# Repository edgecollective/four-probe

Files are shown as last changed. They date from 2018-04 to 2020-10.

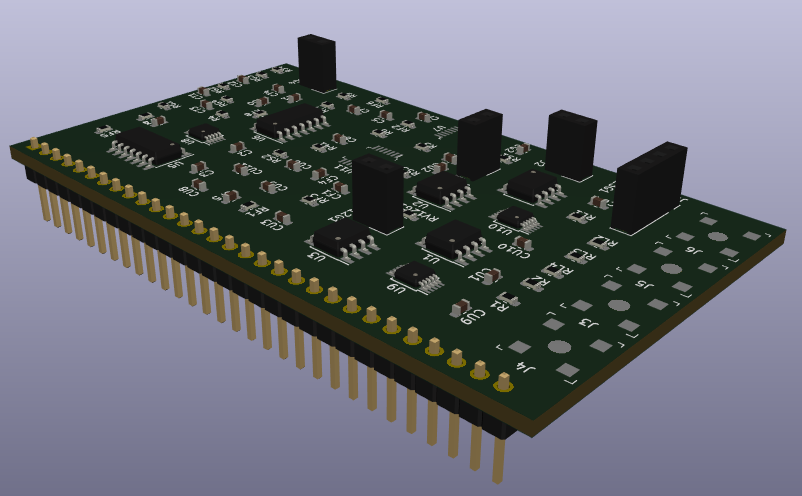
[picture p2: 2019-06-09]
v_0.9/four_probe_0.9_mockup_side.png

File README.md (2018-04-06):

# four-probe

# Timers

- Great examples of using the samd21 timers and interrupts: https://github.com/maxbader/arduino_tools/tree/master/libraries

- Another great example: https://github.com/nebs/arduino-zero-timer-demo/blob/master/src/main.cpp

# Circuit

- Analog Devices "Fully Automatic Self-Calibrated Conductivity Measurements": http://www.analog.com/en/analog-dialogue/articles/fully-automatic-self-calibrated-conductivity-measurement-system.html;  Reference design document: http://www.analog.com/media/en/reference-design-documentation/reference-designs/CN0359.pdf

# Misc Notes

peak detector
https://electronics.stackexchange.com/questions/57866/how-to-sample-and-hold-on-very-narrow-pulse

https://gist.github.com/jdneo/43be30d85080b175cb5aed3500d3f989

arduino zero timer interrupts:
https://forum.arduino.cc/index.php?topic=332275.0

arduino timer library!
https://github.com/avandalen/avdweb_SAMDtimer
http://www.avdweb.nl/arduino/libraries/samd21-timer.html

http://www.avdweb.nl/shop/store.html

http://asf.atmel.com/docs/latest/samr21/html/group__asfdoc__sam0__tcc__group.html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

general reference for samd21:
http://ww1.microchip.com/downloads/en/DeviceDoc/40001882A.pdf

https://forum.arduino.cc/index.php?topic=332275.15
https://forum.arduino.cc/index.php?topic=454243.0 --- intro to the timer

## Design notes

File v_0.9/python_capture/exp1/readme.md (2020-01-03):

used fourprobe_sampler.ino
gain resistor on current = 1000K
printing out:  v23ave, tiave, rave, where rave = v23 ave / (tiave / gain)

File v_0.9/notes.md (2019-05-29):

https://datasheets.maximintegrated.com/en/ds/DG421-DG425.pdf

https://datasheets.maximintegrated.com/en/ds/DG417-DG419.pdf

alternative switch:
https://www.analog.com/media/en/technical-documentation/data-sheets/ADG888.pdf

https://datasheets.maximintegrated.com/en/ds/MAX4699-MAX4702.pdf

four probe
https://www.analog.com/en/analog-dialogue/articles/fully-automatic-self-calibrated-conductivity-measurement-system.html

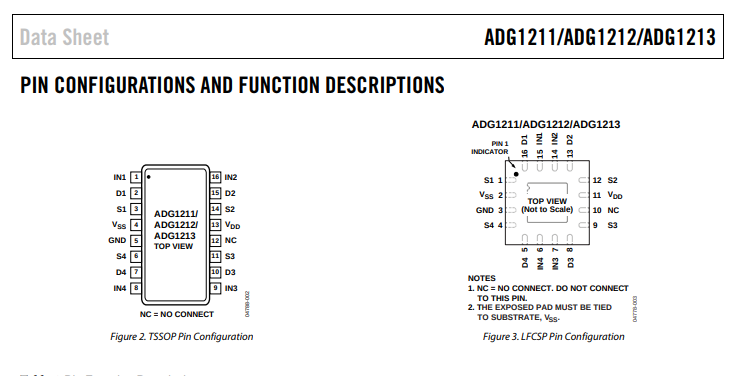
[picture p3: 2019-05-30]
v_0.9/adg1211_pinout.png

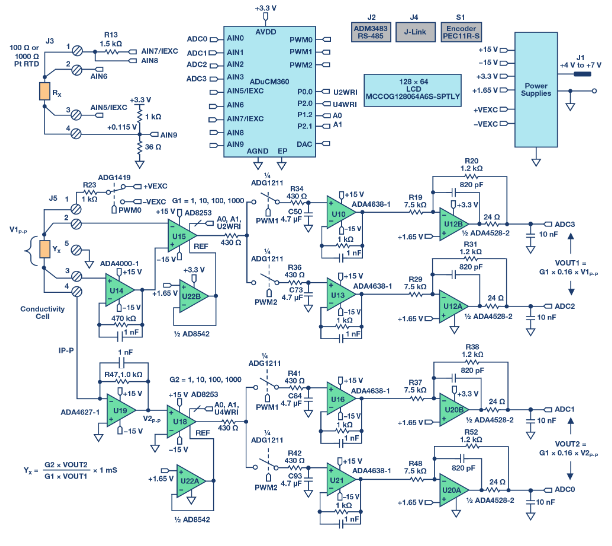
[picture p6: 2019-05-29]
v_0.9/four_probe.png

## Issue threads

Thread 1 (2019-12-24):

Capacitive loading on op-amp

dwblair, 2019-12-24:
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

This might most easily be solved by using the recommended op-amps from Analog Devices in their [conductivity reference circuit](https://www.analog.com/en/analog-dialogue/articles/fully-automatic-self-calibrated-conductivity-measurement-system.html)

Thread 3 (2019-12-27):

Replace GNDREF dual op-amp with one that can provide greater current

dwblair, 2019-12-27:

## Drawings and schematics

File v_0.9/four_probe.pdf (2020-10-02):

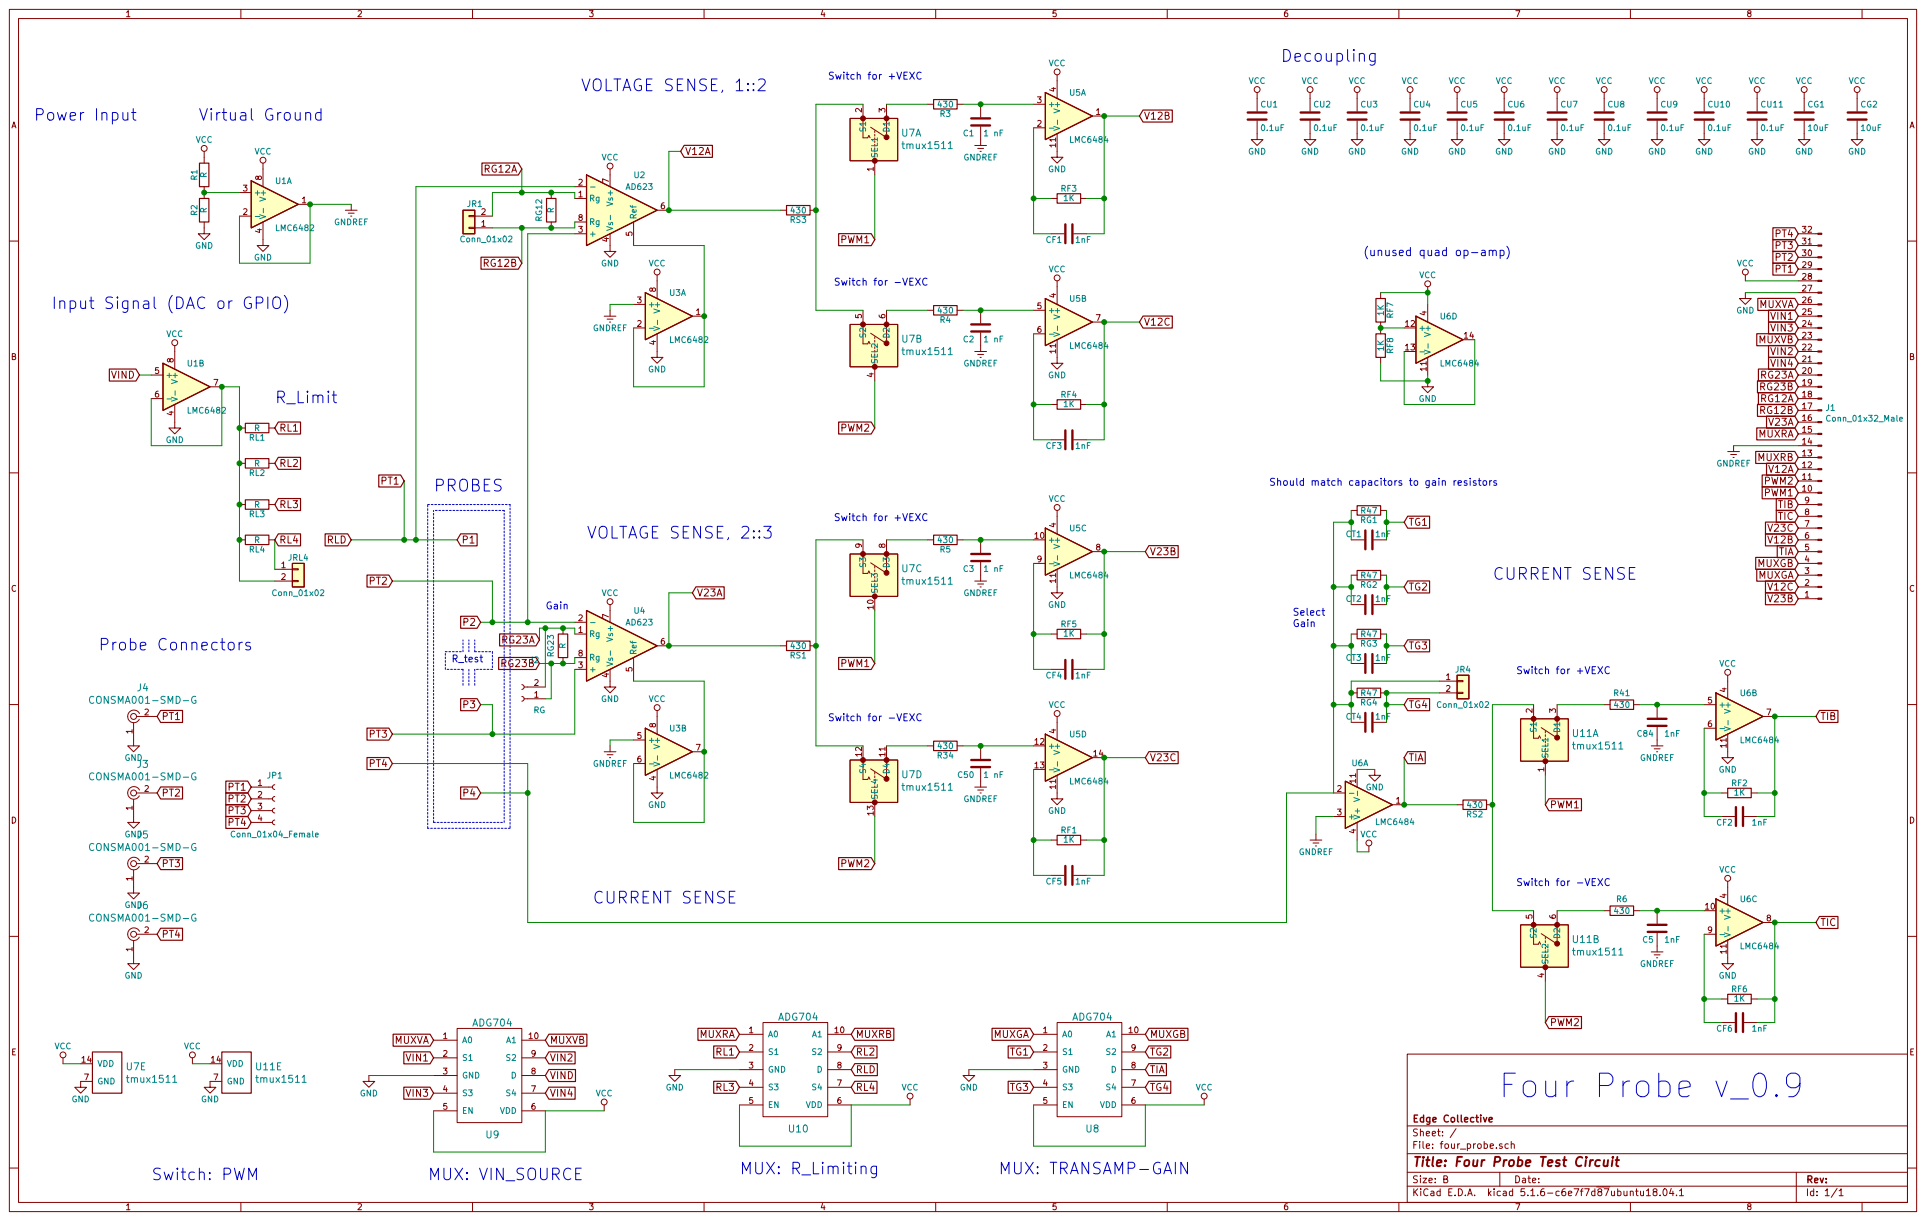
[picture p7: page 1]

(unused quad op-amp)

Input Signal (DAC or GPIO)

Should match capacitors to gain resistors

File: four_probe.sch Sheet: / Edge Collective

Id: 1/1 Title: Four Probe Test Circuit

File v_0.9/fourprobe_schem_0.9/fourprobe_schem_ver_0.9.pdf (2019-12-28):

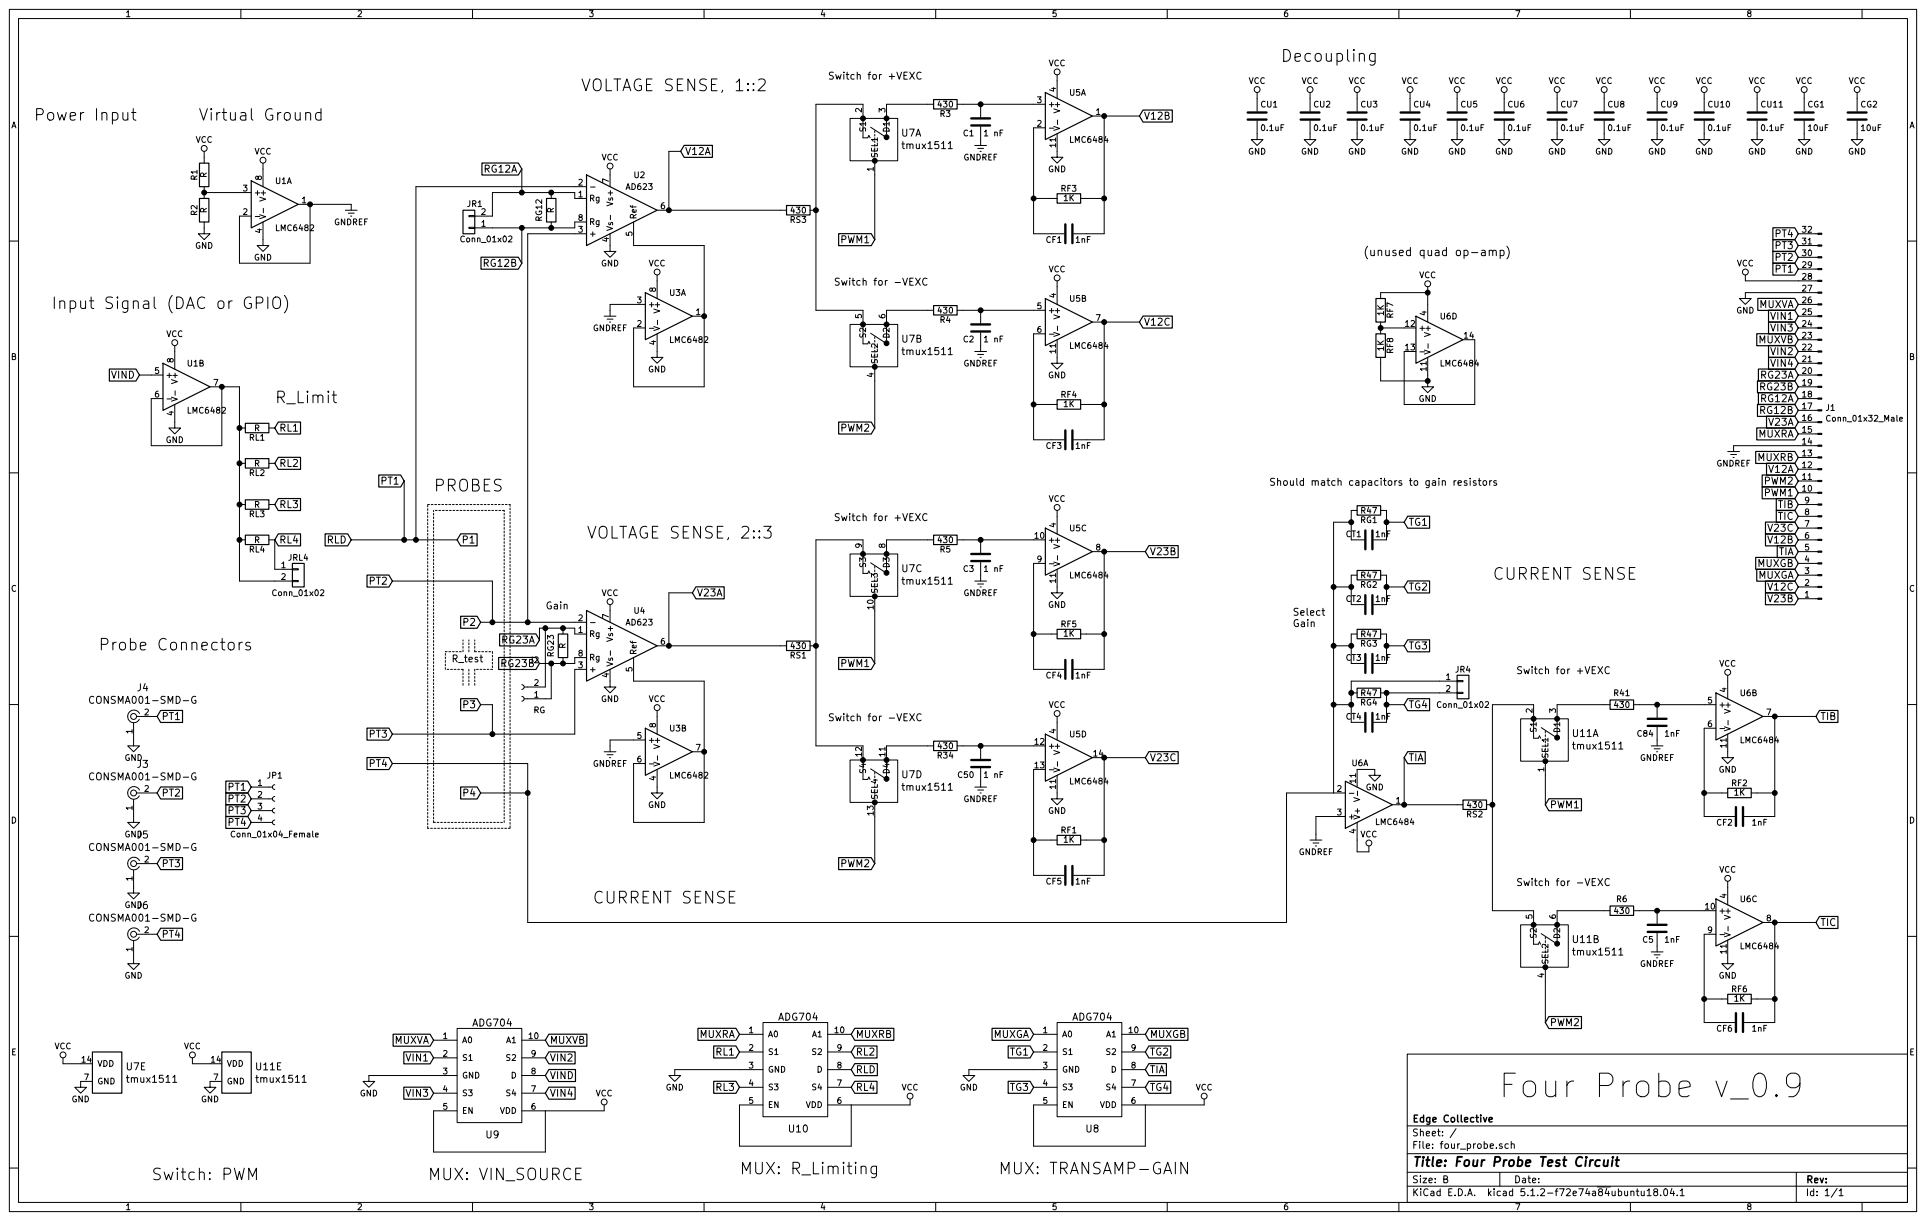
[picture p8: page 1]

(unused quad op-amp) VCC GND

0.1uF VCC GND PT1 PT2 PT3 PT4 VIN4 VIN3 VIN2 VIN1 MUXRA MUXRB

File: four_probe.sch Sheet: / Edge Collective VCCGND GNDREF R1R R2R GND

Id: 1/1 Title: Four Probe Test Circuit

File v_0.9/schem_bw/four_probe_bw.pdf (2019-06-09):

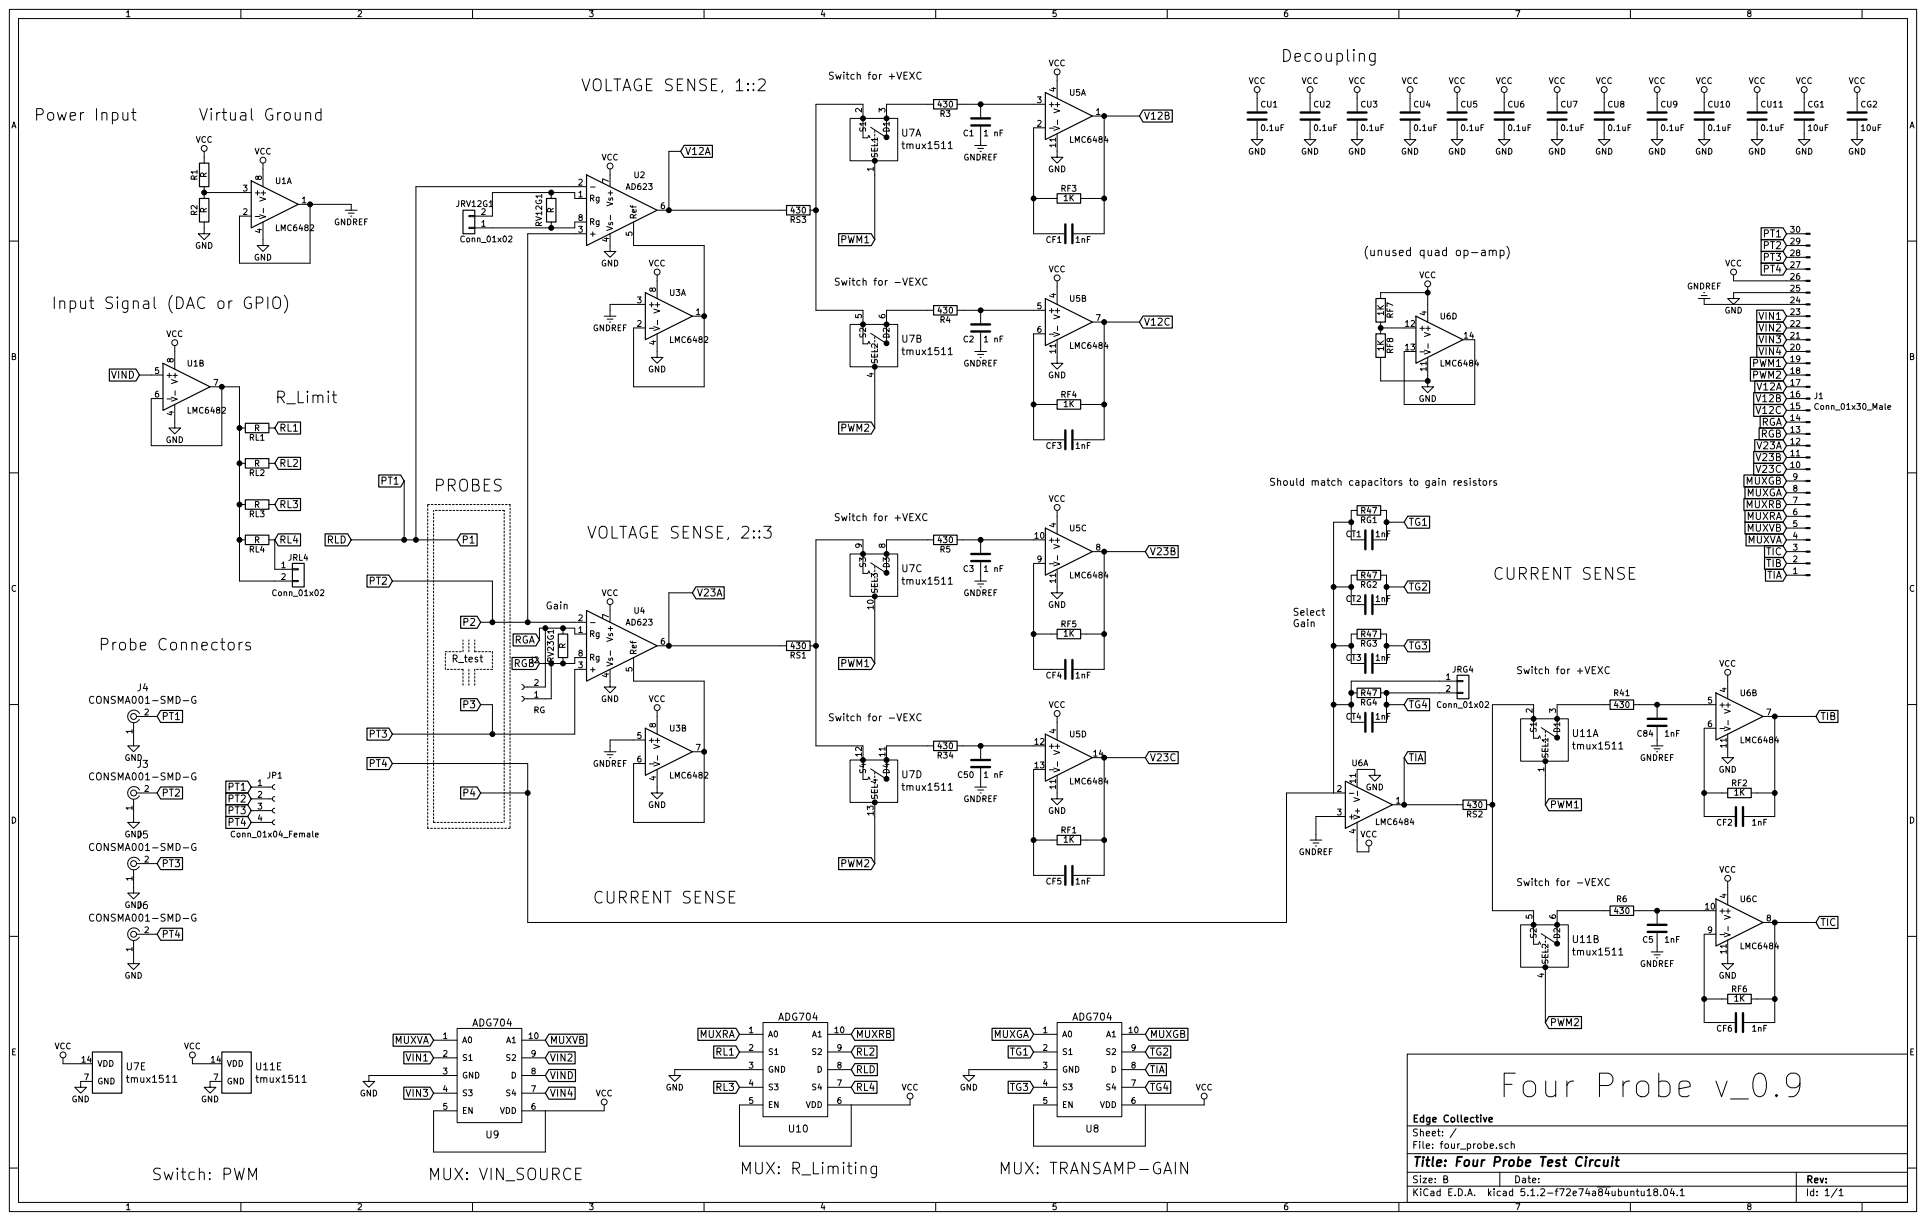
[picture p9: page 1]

(unused quad op-amp) VCC GND

File: four_probe.sch Sheet: / Edge Collective VCCGND GNDREF R1R R2R GND

Id: 1/1 Title: Four Probe Test Circuit

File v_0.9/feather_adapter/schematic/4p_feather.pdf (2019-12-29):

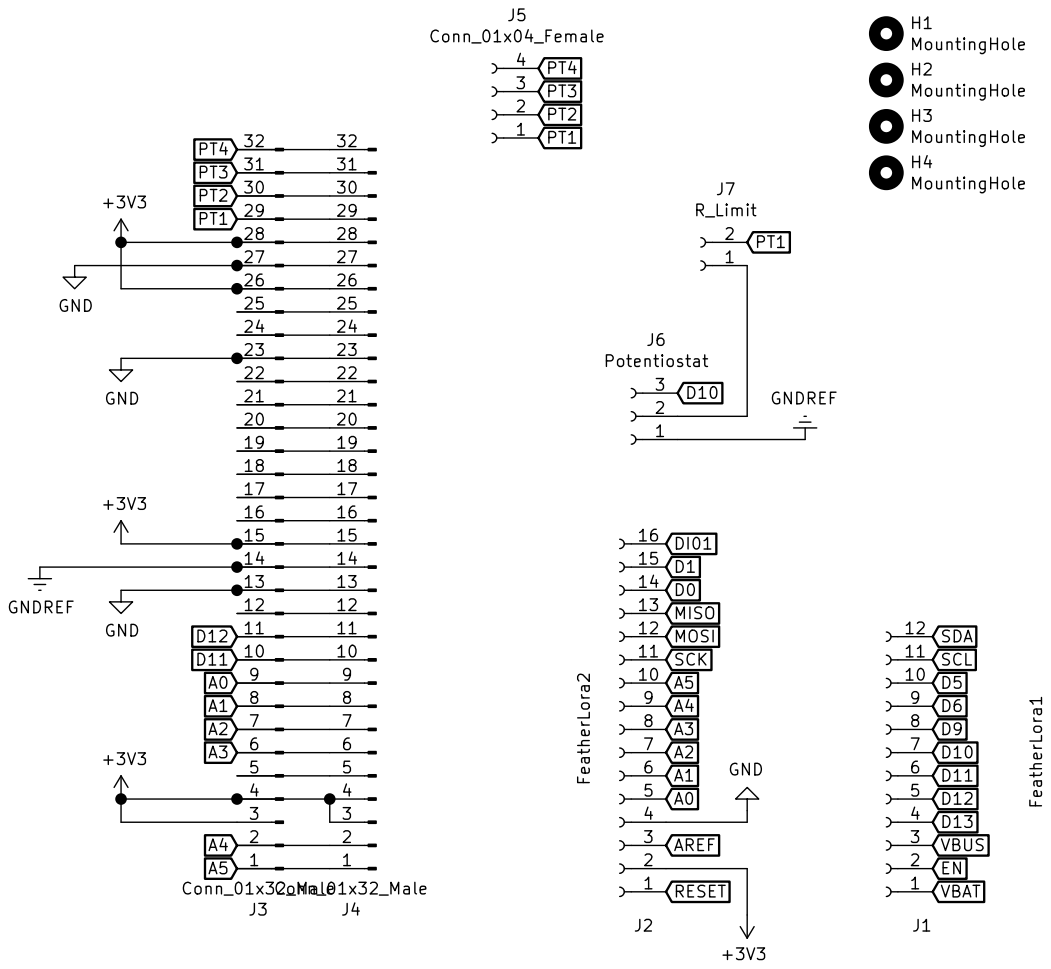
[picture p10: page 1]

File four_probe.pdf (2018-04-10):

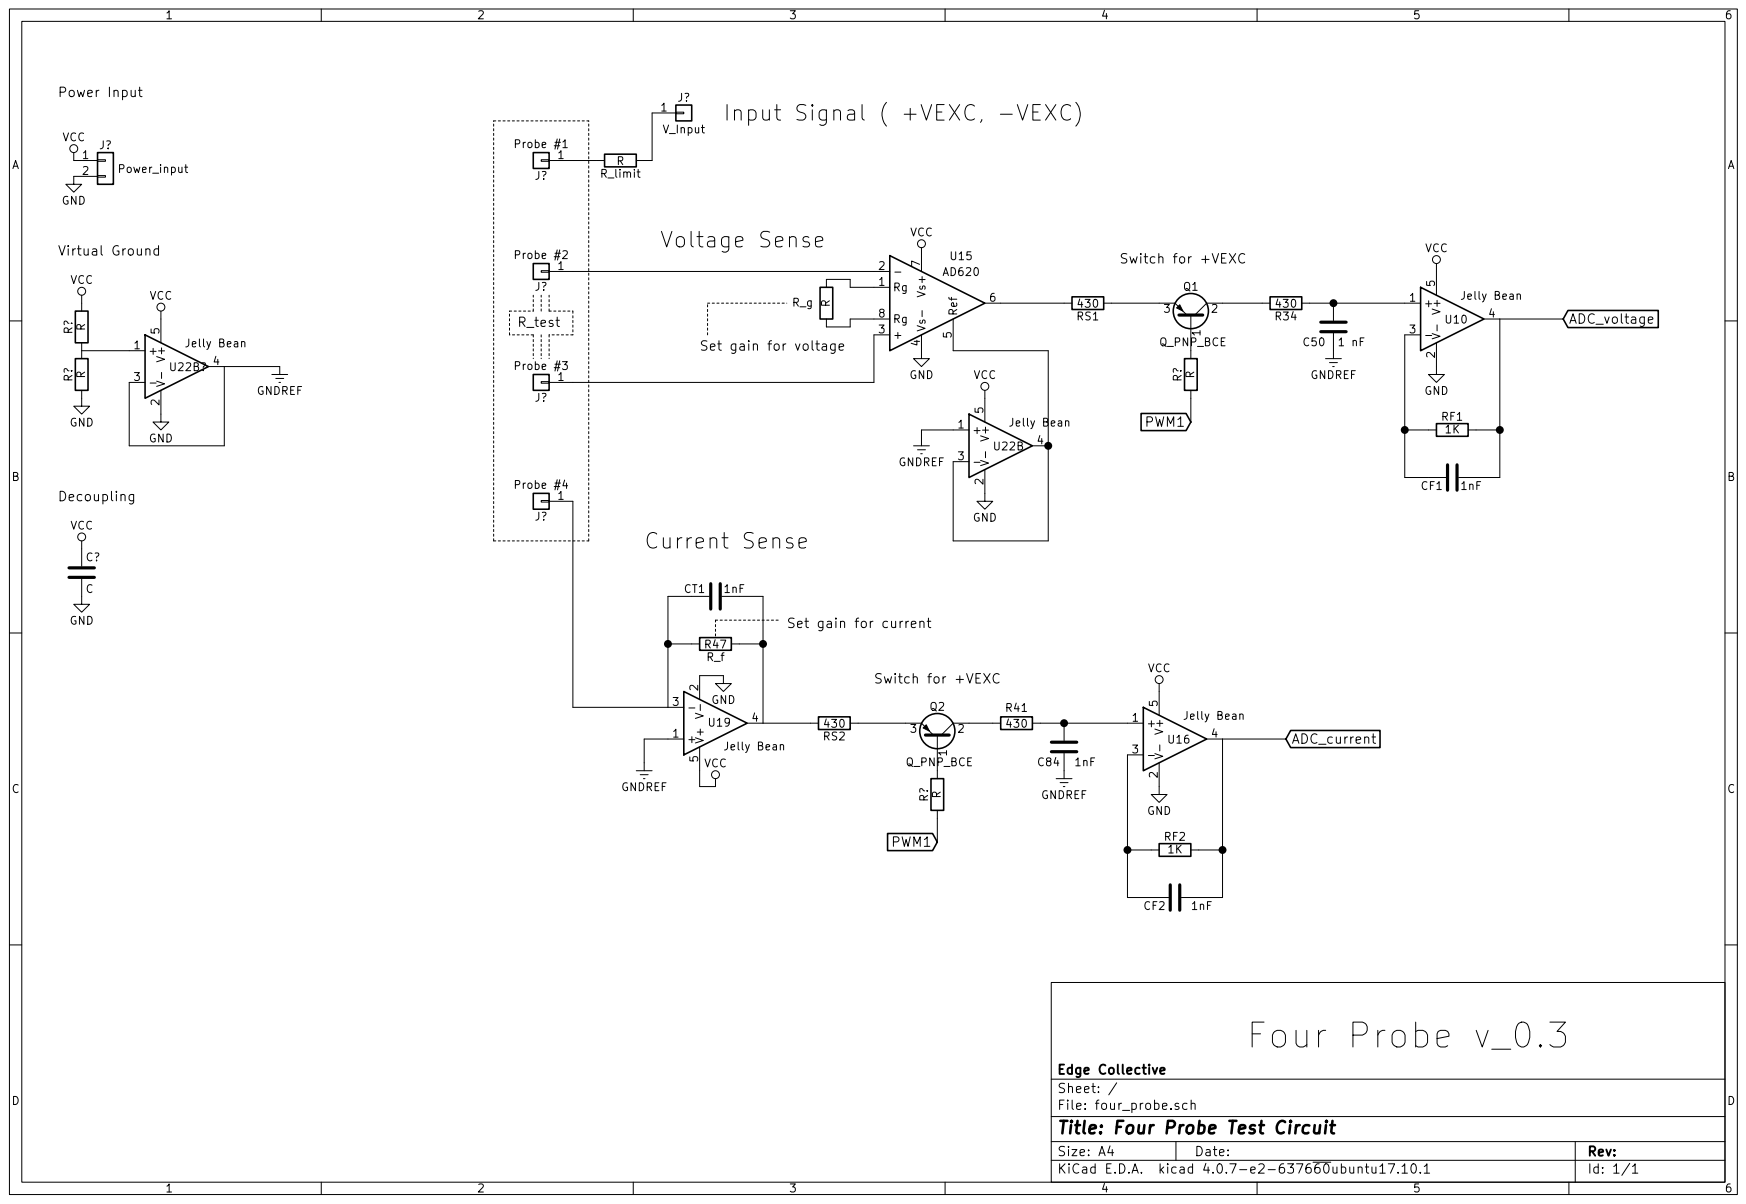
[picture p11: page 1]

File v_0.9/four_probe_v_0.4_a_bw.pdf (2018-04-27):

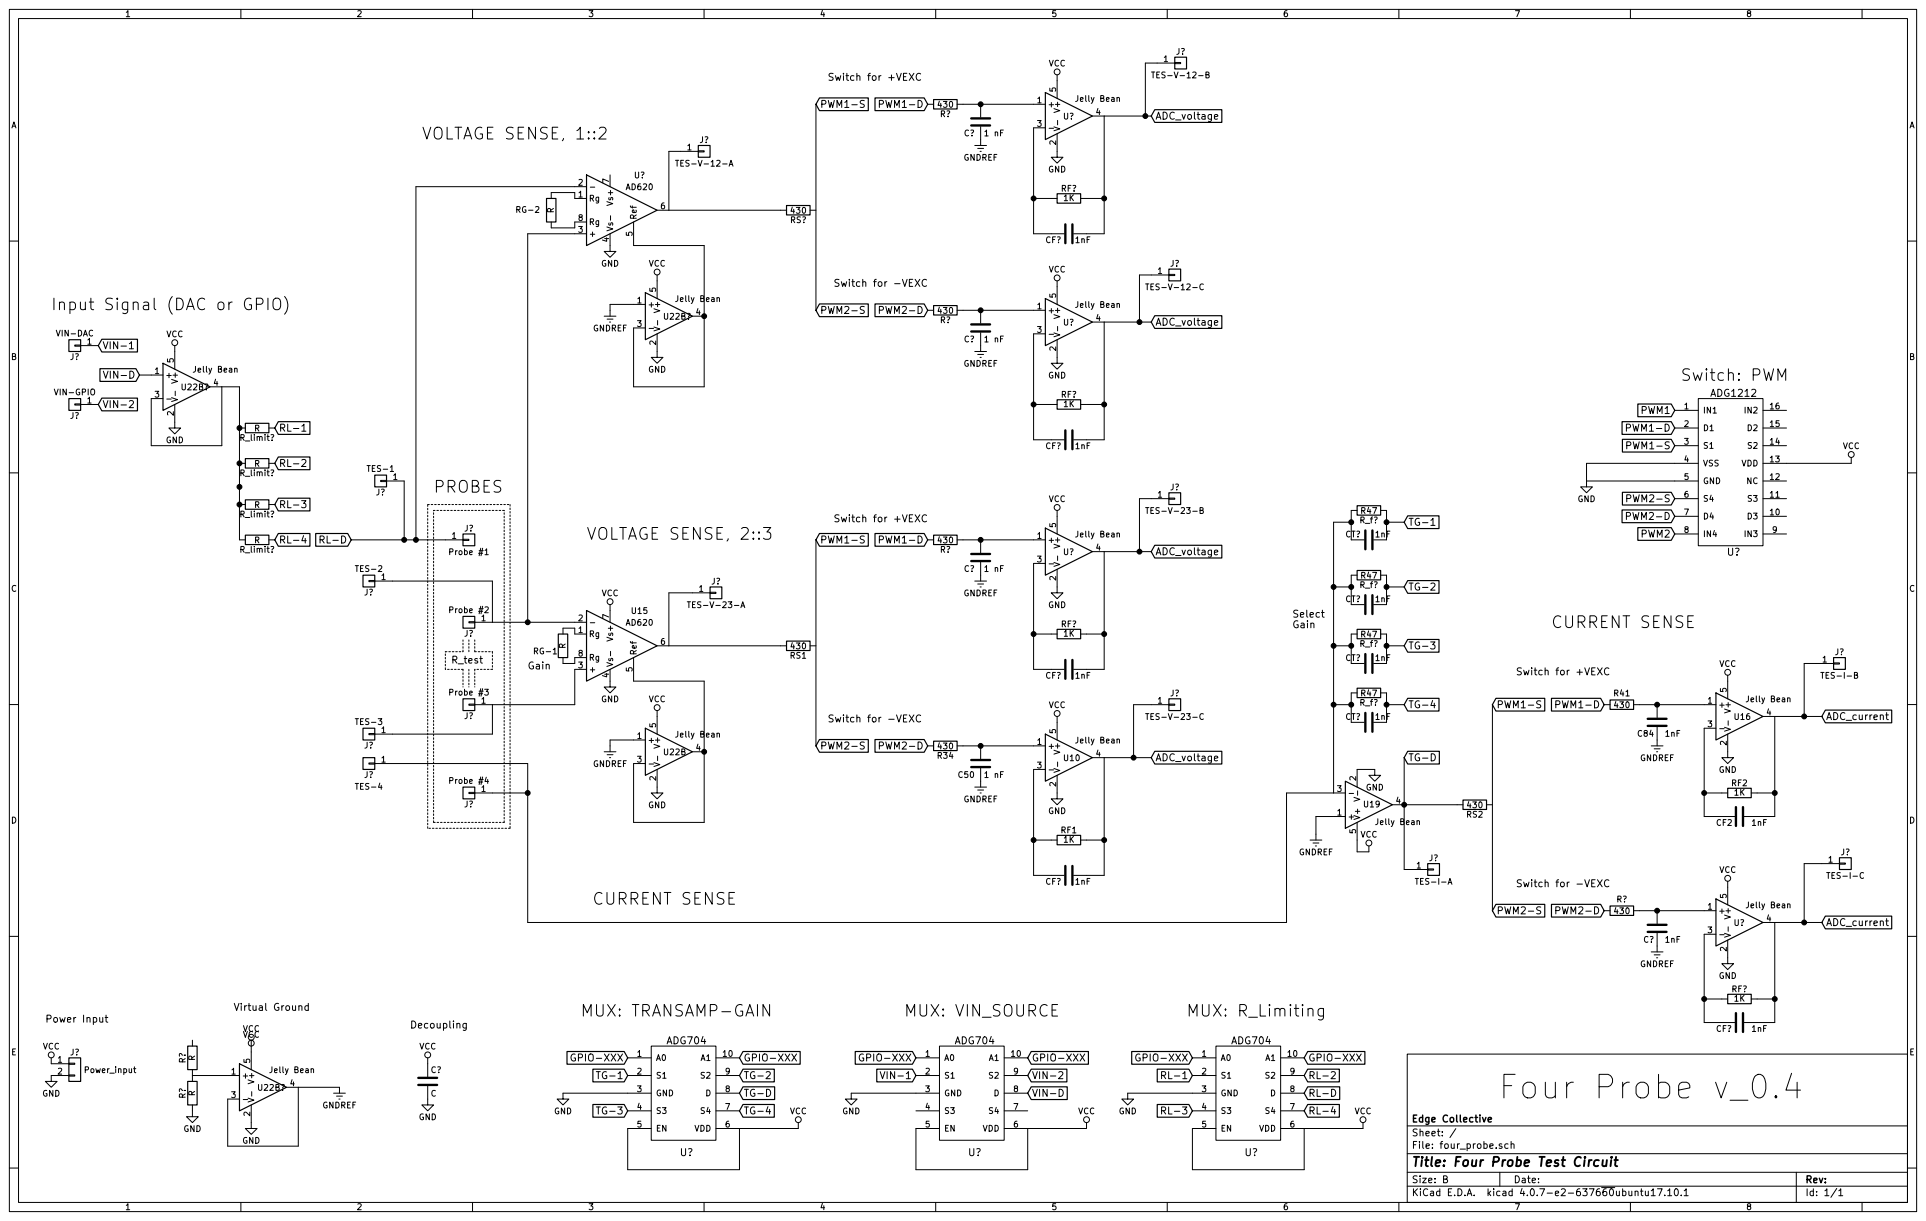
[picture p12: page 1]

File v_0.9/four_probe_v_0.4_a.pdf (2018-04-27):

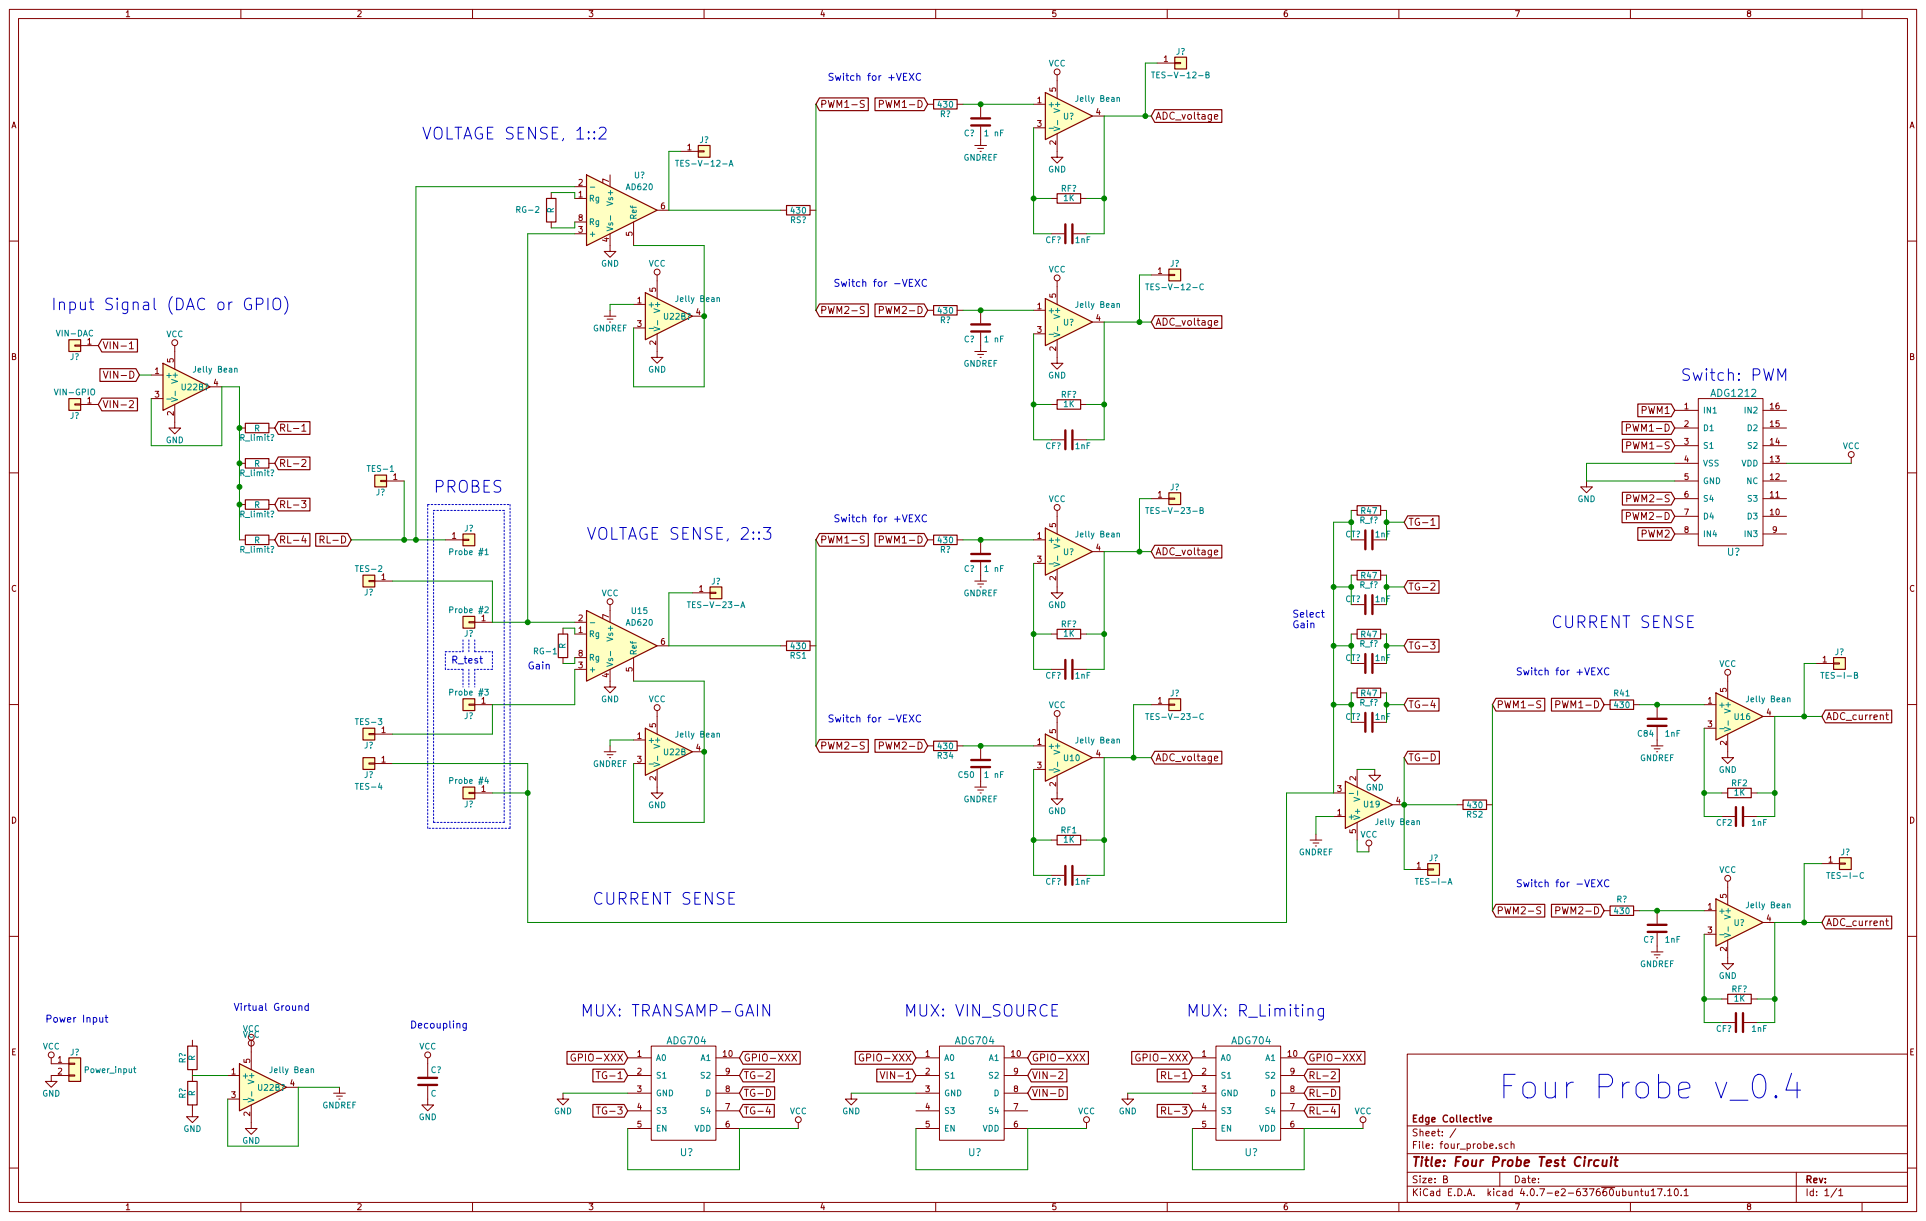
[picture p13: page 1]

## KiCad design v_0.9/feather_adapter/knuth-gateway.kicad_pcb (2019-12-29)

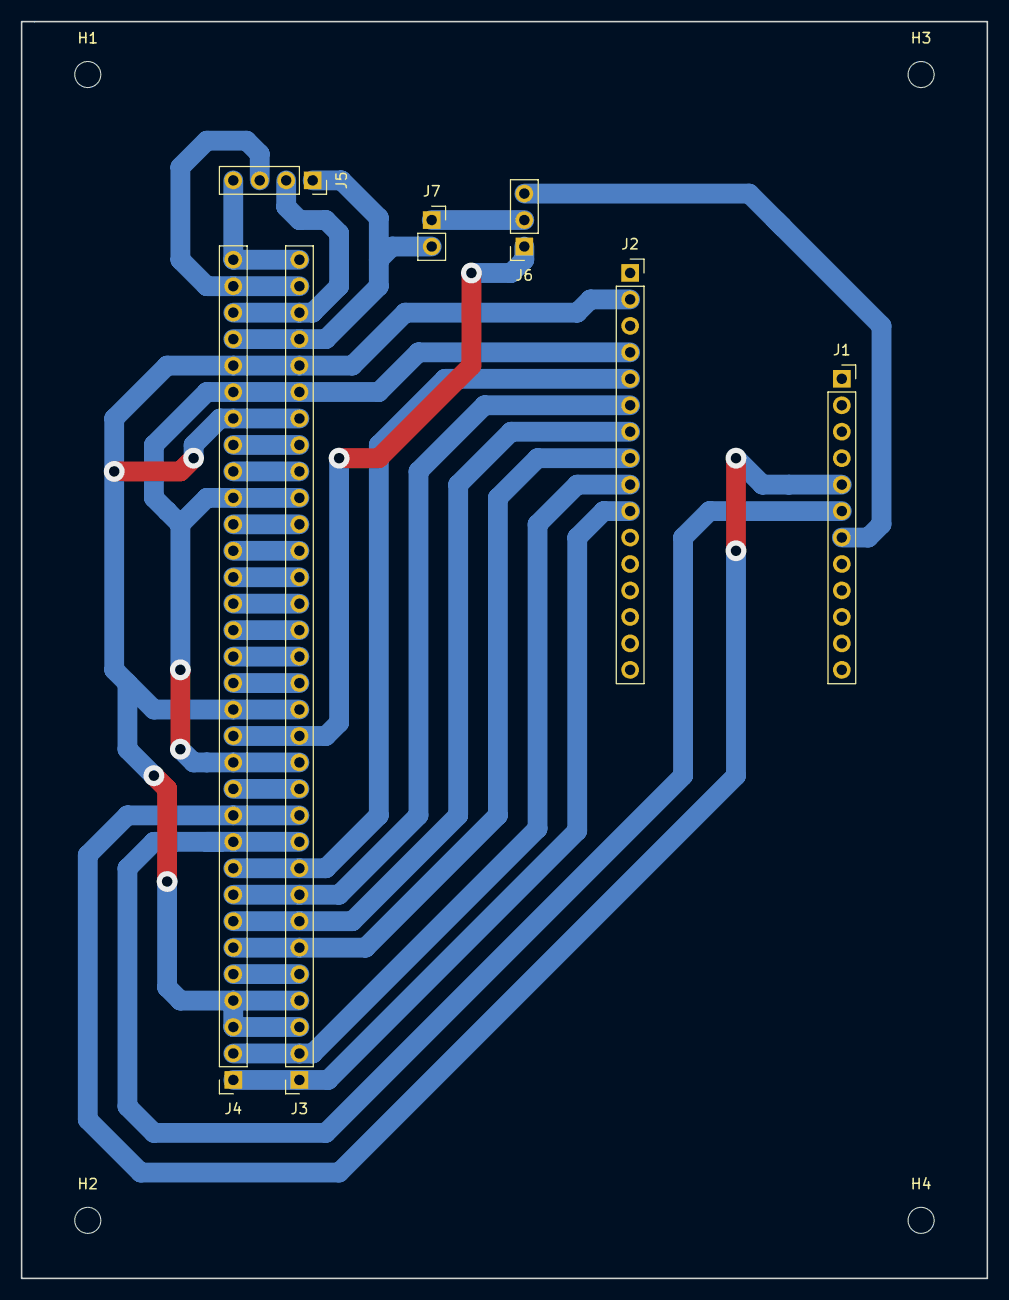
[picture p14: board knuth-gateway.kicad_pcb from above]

Board: 2 copper layers, 92.7 x 120.7 mm, 11 parts (0 on the bottom side), 28 nets.

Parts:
H1, H2, H3, H4: MountingHole; MountingHole_2.5mm
J1: FeatherLora1; PinSocket_1x12_P2.54mm_Vertical
J2: FeatherLora2; PinSocket_1x16_P2.54mm_Vertical
J3, J4: Conn_01x32_Male; PinSocket_1x32_P2.54mm_Vertical
J5: Conn_01x04_Female; PinSocket_1x04_P2.54mm_Vertical
J6: Conn_01x03_Female; PinSocket_1x03_P2.54mm_Vertical
J7: Conn_01x02_Female; PinSocket_1x02_P2.54mm_Vertical

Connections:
+3V3: J2.2, J3.3, J3.4, J3.15, J3.26, J3.28, J4.3, J4.4, J4.15, J4.26, J4.28
A0: J2.5, J3.9, J4.9
A1: J2.6, J3.8, J4.8
A2: J2.7, J3.7, J4.7
A3: J2.8, J3.6, J4.6
A4: J2.9, J3.2, J4.2
A5: J2.10, J3.1, J4.1
D10: J1.7, J6.3
D11: J1.6, J3.10, J4.10
D12: J1.5, J3.11, J4.11
GND: J2.4, J3.13, J3.23, J3.27, J4.13, J4.23, J4.27
GNDREF: J3.14, J4.14, J6.1
unnamed: J3.5, J4.5
unnamed: J3.12, J4.12
unnamed: J3.16, J4.16
unnamed: J3.17, J4.17
unnamed: J3.18, J4.18
unnamed: J3.19, J4.19
unnamed: J3.20, J4.20
unnamed: J3.21, J4.21
unnamed: J3.22, J4.22
unnamed: J3.24, J4.24
unnamed: J3.25, J4.25
unnamed: J6.2, J7.1
PT1: J3.29, J4.29, J5.1, J7.2
PT2: J3.30, J4.30, J5.2
PT3: J3.31, J4.31, J5.3
PT4: J3.32, J4.32, J5.4

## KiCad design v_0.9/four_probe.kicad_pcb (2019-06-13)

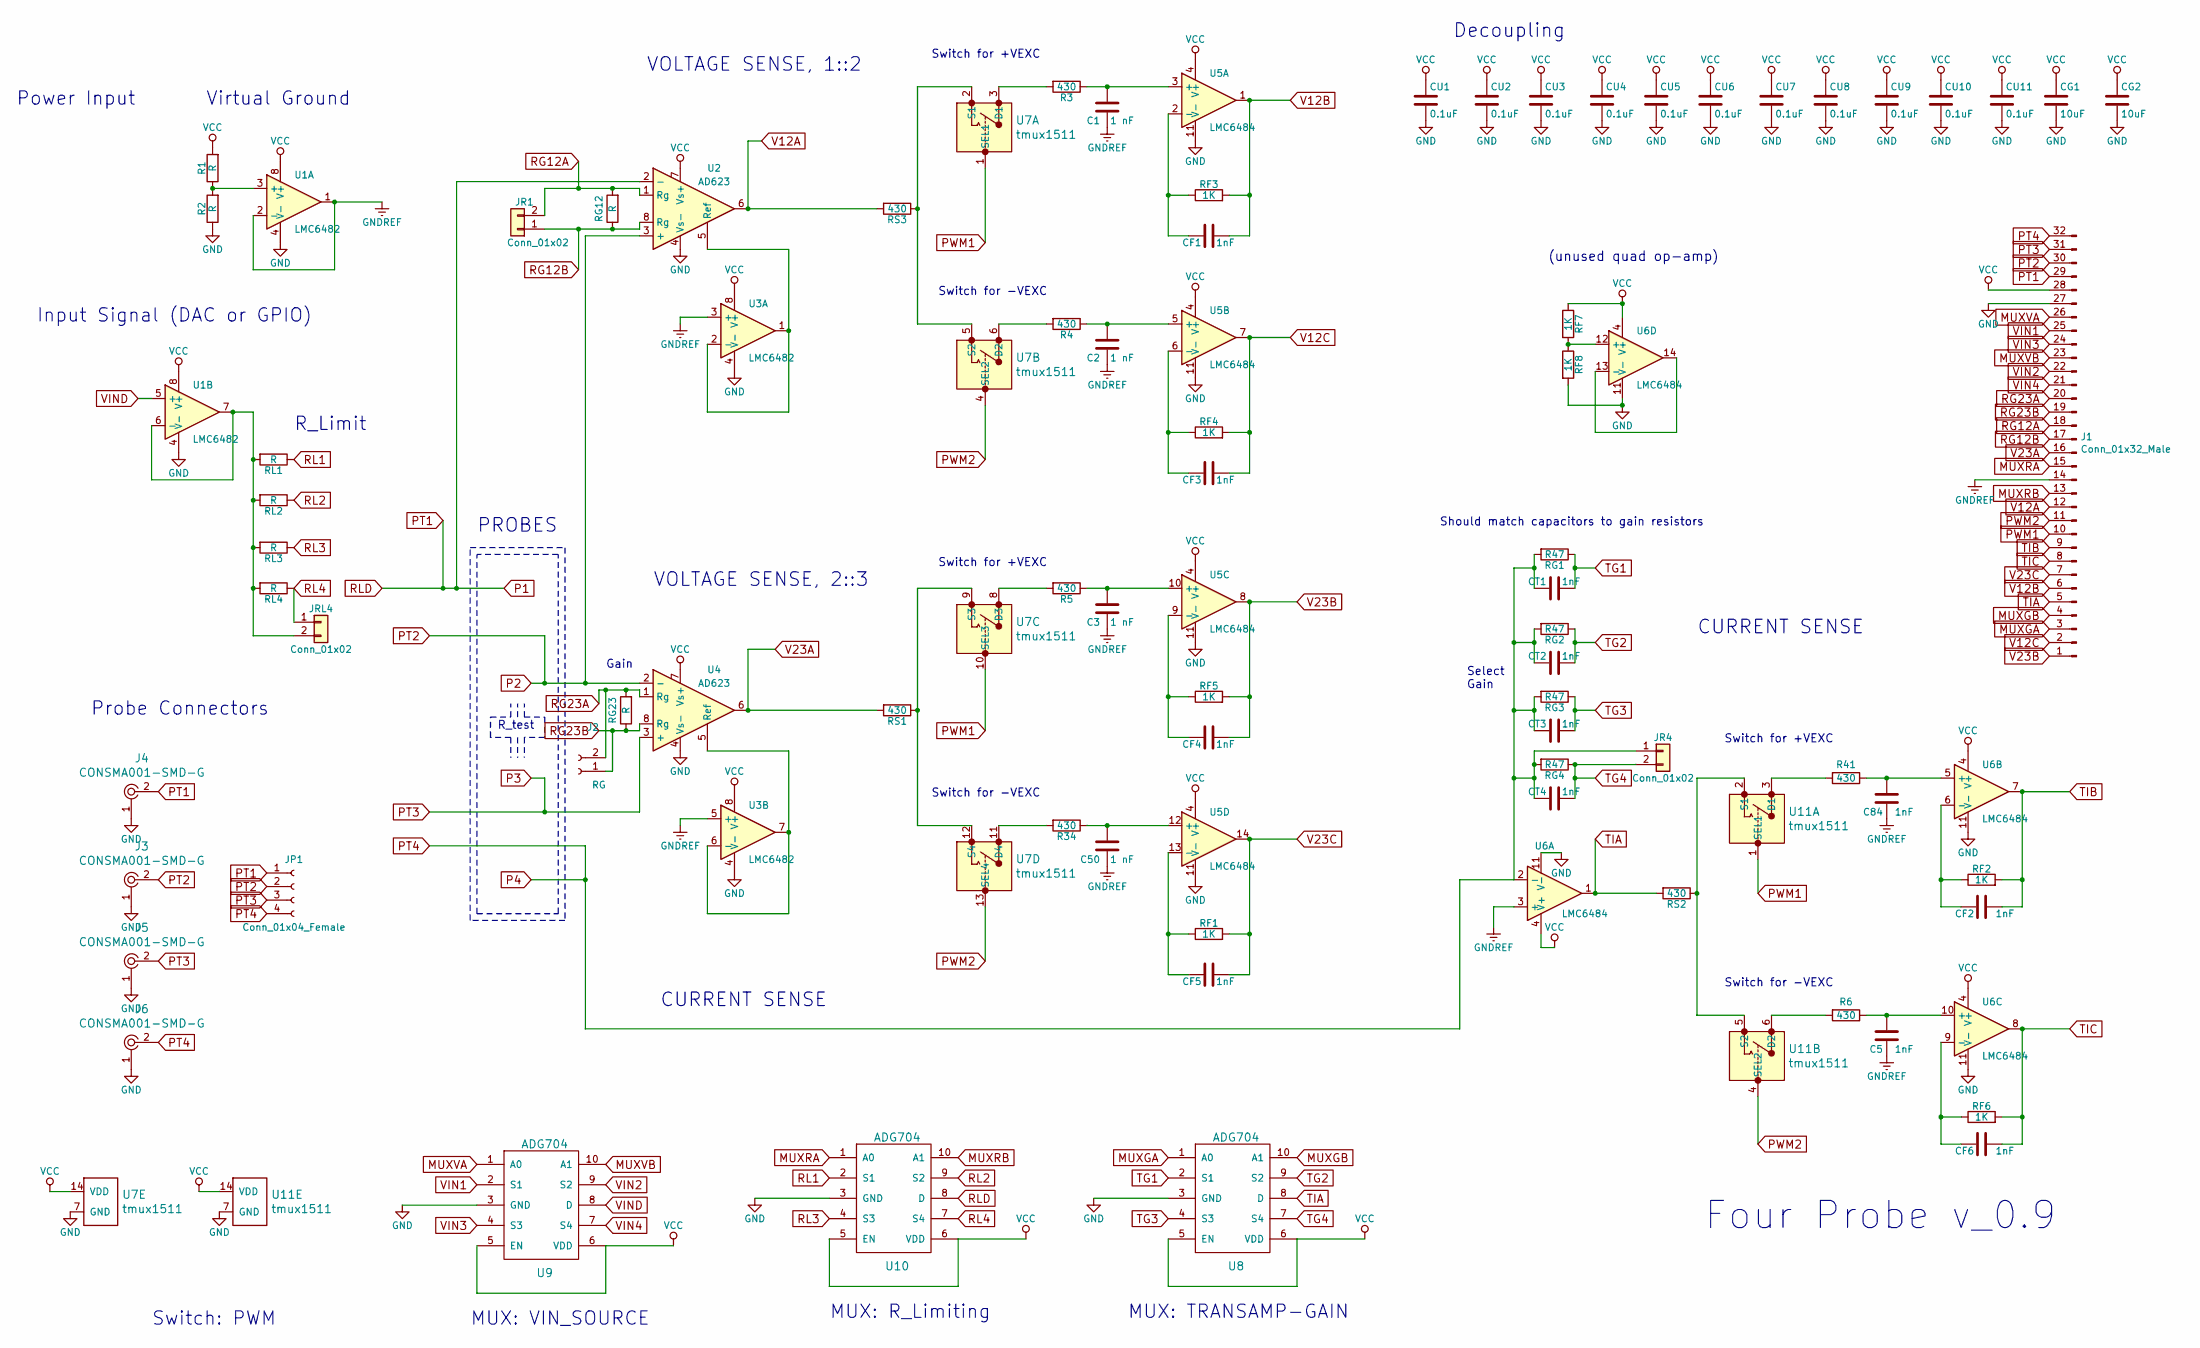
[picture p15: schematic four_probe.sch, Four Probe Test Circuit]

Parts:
C1, C2, C3, C50: 1 nF; C_0603_1608Metric
C5, C84: 1nF; C_0603_1608Metric
CF1, CF2, CF3, CF4, CF5, CF6: 1nF; C_0603_1608Metric
CG1, CG2: 10uF; C_0603_1608Metric
CT1, CT2, CT3, CT4: 1nF; C_0603_1608Metric
CU1, CU2, CU3, CU4, CU5, CU6, CU7, CU8, CU9, CU10, CU11: 0.1uF; C_0603_1608Metric
J1: Conn_01x32_Male; PinHeader_1x32_P2.54mm_Vertical
J2: RG; PinSocket_1x02_P2.54mm_Vertical
J3, J4, J5, J6: CONSMA001-SMD-G; RF_SMA_Receptical_Vertical_CONSMA001-SMD-G; MPN CONSMA001-SMD-G; Digi-Key_PN CONSMA001-SMD-G-ND
JP1: Conn_01x04_Female; PinSocket_1x04_P2.54mm_Vertical
JR1, JR4: Conn_01x02; PinSocket_1x02_P2.54mm_Vertical
JRL4: Conn_01x02; PinSocket_1x02_P2.54mm_Vertical
R1, R2: R; R_0603_1608Metric
R3, R4, R5, R6, R34, R41: 430; R_0603_1608Metric
RF1, RF2, RF3, RF4, RF5, RF6, RF7, RF8: 1K; R_0603_1608Metric
RG1, RG2, RG3, RG4: R47; R_0603_1608Metric
RG12, RG23: R; R_0603_1608Metric
RL1, RL2, RL3, RL4: R; R_0603_1608Metric
RS1, RS2, RS3: 430; R_0603_1608Metric
U1, U3: LMC6482; SOIC-8_3.9x4.9mm_P1.27mm
U2, U4: AD623; SOIC-8_3.9x4.9mm_P1.27mm
U5, U6: LMC6484; SOIC-14_3.9x8.7mm_P1.27mm
U7, U11: tmux1511; TSSOP-14_W4.4mm
U8, U9, U10: ADG704; MSOP-10_3x3mm_P0.5mm

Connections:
GND: CG1.2, CG2.2, CU1.2, CU2.2, CU3.2, CU4.2, CU5.2, CU6.2, CU7.2, CU8.2, CU9.2, CU10.2, CU11.2, J1.27, J3.1, J4.1, J5.1, J6.1, R2.1, RF8.2, U1.4 (V-), U2.4 (Vs-), U3.4 (V-), U4.4 (Vs-), U5.11 (V-), U6.11 (V-), U7.7 (GND), U8.3 (GND), U9.3 (GND), U10.3 (GND), U11.7 (GND)
GNDREF: C1.1, C2.1, C3.1, C5.1, C50.1, C84.1, J1.14, U1.1, U1.2 (-), U3.3 (+), U3.5 (+), U6.3 (+)
MUXGA: J1.3, U8.1 (A0)
MUXGB: J1.4, U8.10 (A1)
MUXRA: J1.15, U10.1 (A0)
MUXRB: J1.13, U10.10 (A1)
MUXVA: J1.26, U9.1 (A0)
MUXVB: J1.23, U9.10 (A1)
unnamed: C1.2, R3.1, U5.3 (+)
unnamed: C2.2, R4.1, U5.5 (+)
unnamed: C3.2, R5.1, U5.10 (+)
unnamed: C5.2, R6.1, U6.10 (+)
unnamed: C50.2, R34.1, U5.12 (+)
unnamed: C84.2, R41.1, U6.5 (+)
unnamed: CF1.2, RF3.1, U5.2 (-)
unnamed: CF2.2, RF2.1, U6.6 (-)
unnamed: CF3.2, RF4.1, U5.6 (-)
unnamed: CF4.2, RF5.1, U5.9 (-)
unnamed: CF5.2, RF1.1, U5.13 (-)
unnamed: CF6.2, RF6.1, U6.9 (-)
unnamed: JRL4.2, RL1.2, RL2.2, RL3.2, RL4.2, U1.6 (-), U1.7
unnamed: R1.1, R2.2, U1.3 (+)
unnamed: R3.2, U7.3 (D1)
unnamed: R4.2, U7.6 (D2)
unnamed: R5.2, U7.8 (D3)
unnamed: R6.2, U11.6 (D2)
unnamed: R34.2, U7.11 (D4)
unnamed: R41.2, U11.3 (D1)
unnamed: RF7.2, RF8.1, U6.12 (+)
unnamed: RS1.1, U7.9 (S3), U7.12 (S4)
unnamed: RS2.1, U11.2 (S1), U11.5 (S2)
unnamed: RS3.1, U7.2 (S1), U7.5 (S2)
unnamed: U2.5 (Ref), U3.1, U3.2 (-)
unnamed: U3.6 (-), U3.7, U4.5 (Ref)
unnamed: U6.13 (-), U6.14
P1: J1.29, J4.2, JP1.1, U2.2 (-), U10.8 (D)
P2: J1.30, J3.2, JP1.2, U2.3 (+), U4.2 (-)
P3: J1.31, J5.2, JP1.3, U4.3 (+)
P4: CT1.2, CT2.2, CT3.2, CT4.2, J1.32, J6.2, JP1.4, JR4.1, RG1.2, RG2.2, RG3.2, RG4.2, U6.2 (-)
PWM1: J1.10, U7.1 (SEL1), U7.10 (SEL3), U11.1 (SEL1)
PWM2: J1.11, U7.4 (SEL2), U7.13 (SEL4), U11.4 (SEL2)
RG12A: J1.18, JR1.2, RG12.2, U2.1 (Rg)
RG12B: J1.17, JR1.1, RG12.1, U2.8 (Rg)
RG23A: J1.20, J2.2, RG23.2, U4.1 (Rg)
RG23B: J1.19, J2.1, RG23.1, U4.8 (Rg)
RL1: RL1.1, U10.2 (S1)
RL2: RL2.1, U10.9 (S2)
RL3: RL3.1, U10.4 (S3)
RL4: JRL4.1, RL4.1, U10.7 (S4)
TG1: CT1.1, RG1.1, U8.2 (S1)
TG2: CT2.1, RG2.1, U8.9 (S2)
TG3: CT3.1, RG3.1, U8.4 (S3)
TG4: CT4.1, JR4.2, RG4.1, U8.7 (S4)
TIA: J1.5, RS2.2, U6.1, U8.8 (D)
TIB: CF2.1, J1.9, RF2.2, U6.7
TIC: CF6.1, J1.8, RF6.2, U6.8
V12A: J1.12, RS3.2, U2.6
V12B: CF1.1, J1.6, RF3.2, U5.1
V12C: CF3.1, J1.2, RF4.2, U5.7
V23A: J1.16, RS1.2, U4.6
V23B: CF4.1, J1.1, RF5.2, U5.8
V23C: CF5.1, J1.7, RF1.2, U5.14
VCC: CG1.1, CG2.1, CU1.1, CU2.1, CU3.1, CU4.1, CU5.1, CU6.1, CU7.1, CU8.1, CU9.1, CU10.1, CU11.1, J1.28, R1.2, RF7.1, U1.8 (V+), U2.7 (Vs+), U3.8 (V+), U4.7 (Vs+), U5.4 (V+), U6.4 (V+), U7.14 (VDD), U8.5 (EN), U8.6 (VDD), U9.5 (EN), U9.6 (VDD), U10.5 (EN), U10.6 (VDD), U11.14 (VDD)
VIN1: J1.25, U9.2 (S1)
VIN2: J1.22, U9.9 (S2)
VIN3: J1.24, U9.4 (S3)
VIN4: J1.21, U9.7 (S4)
VIND: U1.5 (+), U9.8 (D)

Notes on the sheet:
Input Signal (DAC or GPIO)
R_test
Gain
Switch for +VEXC
Switch for -VEXC
Select Gain
MUX: R_Limiting
Switch: PWM
MUX: VIN_SOURCE
MUX: TRANSAMP-GAIN
CURRENT SENSE
VOLTAGE SENSE, 1::2
VOLTAGE SENSE, 2::3
PROBES
Four Probe v_0.9
Virtual Ground
R_Limit
Power Input
Decoupling
(unused quad op-amp)
Should match capacitors to gain resistors
Probe Connectors

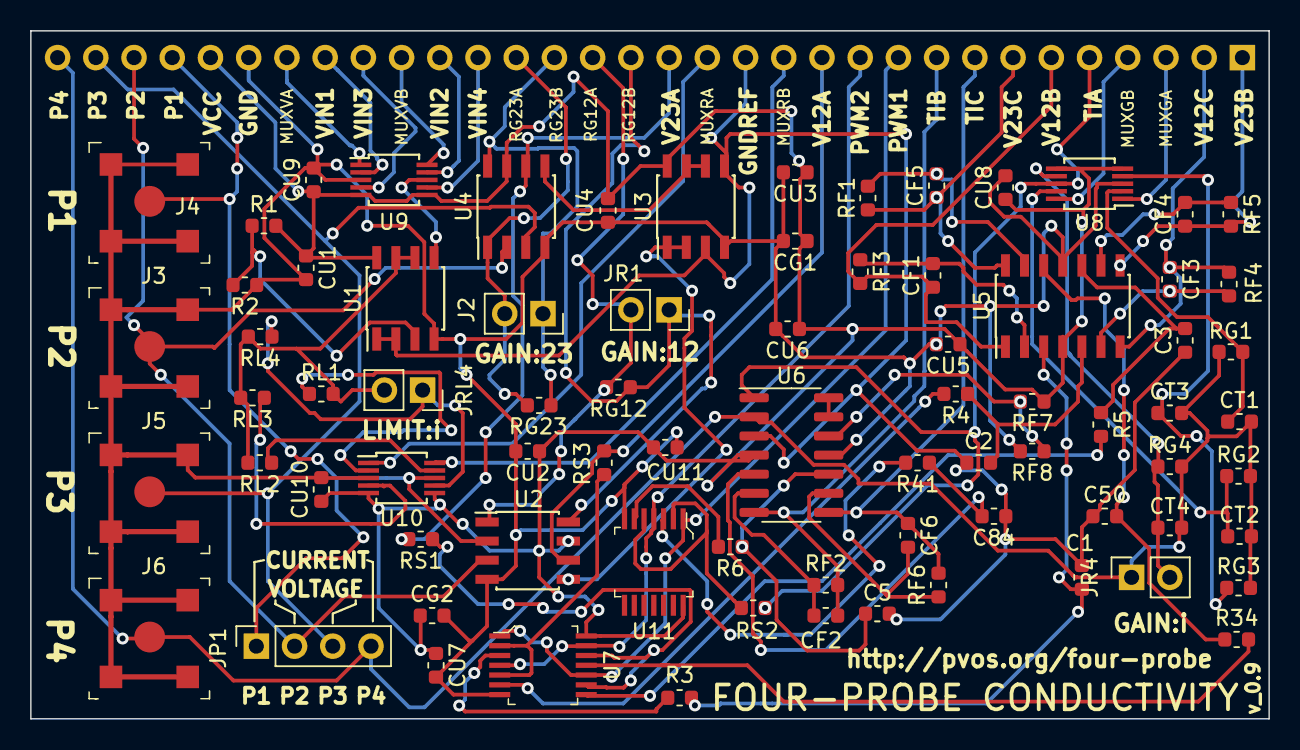
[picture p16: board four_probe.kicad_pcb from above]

Board: 2 copper layers, 82.3 x 45.7 mm, 79 parts (1 on the bottom side), 68 nets.

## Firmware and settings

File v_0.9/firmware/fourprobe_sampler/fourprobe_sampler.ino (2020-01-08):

#include <Arduino.h>
#include "Adafruit_ZeroTimer.h" // https://github.com/dwblair/Adafruit_ZeroTimer

// timer 3 ----------------------

float freq3 = 10000; // 10 Hz

volatile bool togglepin = false;
volatile bool togglepin2 = false;


int fourcounter = 0;

int timer3LED = 10;

int highswitchLED = 11;
int lowswitchLED = 12;

Adafruit_ZeroTimer zt3 = Adafruit_ZeroTimer(3);

void TC3_Handler(){
  Adafruit_ZeroTimer::timerHandler(3);
}



// timer 4 ----------------------

float freq4 = freq3*8; // 10 Hz


Adafruit_ZeroTimer zt4 = Adafruit_ZeroTimer(4);

void TC4_Handler(){
  Adafruit_ZeroTimer::timerHandler(4);
}


void Timer4Callback0()
{
  
//Serial.println(fourcounter);
if (fourcounter==0) {

    digitalWrite(timer3LED, HIGH);
digitalWrite(highswitchLED, LOW);
digitalWrite(lowswitchLED, LOW);

}

if (fourcounter==1) {

    digitalWrite(timer3LED, HIGH);
    digitalWrite(highswitchLED, LOW);
    digitalWrite(lowswitchLED, LOW);


}


if (fourcounter==2) {

    digitalWrite(timer3LED, HIGH);
    digitalWrite(highswitchLED, HIGH);
    digitalWrite(lowswitchLED, LOW);


}

else if (fourcounter==3) {

    digitalWrite(timer3LED, HIGH);
    digitalWrite(highswitchLED, LOW);
        digitalWrite(lowswitchLED, LOW);


}

else if (fourcounter==4) {

    digitalWrite(timer3LED, LOW);
        digitalWrite(highswitchLED, LOW);
        digitalWrite(lowswitchLED, LOW);

}


else if (fourcounter==5) {

        digitalWrite(highswitchLED, LOW);
    digitalWrite(lowswitchLED, LOW);
    digitalWrite(timer3LED, LOW);

}

else if (fourcounter==6) {

    digitalWrite(timer3LED, LOW);
     digitalWrite(highswitchLED, LOW);
    digitalWrite(lowswitchLED, HIGH);

}


else if (fourcounter==7) {

    digitalWrite(lowswitchLED, LOW);
    digitalWrite(timer3LED, LOW);
    digitalWrite(highswitchLED, LOW);

}


  fourcounter++;

if (fourcounter==8) {
  fourcounter=0;
}
  
  
}

void setup() {

  analogReadResolution(12);

  
  pinMode(timer3LED, OUTPUT);
  pinMode(highswitchLED, OUTPUT);
pinMode(lowswitchLED, OUTPUT);

  digitalWrite(highswitchLED, LOW);
    digitalWrite(lowswitchLED, LOW);
    
  Serial.begin(9600);
  //while (!Serial) {
   // delay(10);
  //}



  // for timer 4 ---------------------------------------

  
  //Serial.println("Timer callback tester");

  //Serial.print("Desired freq4 (Hz):");
  //Serial.println(freq4);

   // Set up the flexible divider/compare
  uint8_t divider  = 1;
  uint16_t compare = 0;
  tc_clock_prescaler prescaler = TC_CLOCK_PRESCALER_DIV1;


  if ((freq4 < 24000000) && (freq4 > 800)) {
    divider = 1;
    prescaler = TC_CLOCK_PRESCALER_DIV1;
    compare = 48000000/freq4;
  } else if (freq4 > 400) {
    divider = 2;
    prescaler = TC_CLOCK_PRESCALER_DIV2;
    compare = (48000000/2)/freq4;
  } else if (freq4 > 200) {
    divider = 4;
    prescaler = TC_CLOCK_PRESCALER_DIV4;
    compare = (48000000/4)/freq4;
  } else if (freq4 > 100) {
    divider = 8;
    prescaler = TC_CLOCK_PRESCALER_DIV8;
    compare = (48000000/8)/freq4;
  } else if (freq4 > 50) {
    divider = 16;
    prescaler = TC_CLOCK_PRESCALER_DIV16;
    compare = (48000000/16)/freq4;
  } else if (freq4 > 12) {
    divider = 64;
    prescaler = TC_CLOCK_PRESCALER_DIV64;
    compare = (48000000/64)/freq4;
  } else if (freq4 > 3) {
    divider = 256;
    prescaler = TC_CLOCK_PRESCALER_DIV256;
    compare = (48000000/256)/freq4;
  } else if (freq4 >= 0.75) {
    divider = 1024;
    prescaler = TC_CLOCK_PRESCALER_DIV1024;
    compare = (48000000/1024)/freq4;
  } else {
    Serial.println("Invalid freq4uency");
    while (1) delay(10);
  }

  //Serial.println("Timer 4:");
 // Serial.print("Divider:"); Serial.println(divider);
 // Serial.print("Compare:"); Serial.println(compare);
 // Serial.print("Final freq4:"); Serial.println((int)(48000000/compare));

  zt4.enable(false);
  zt4.configure(prescaler,       // prescaler
          TC_COUNTER_SIZE_16BIT,       // bit width of timer/counter
          TC_WAVE_GENERATION_MATCH_PWM // freq3uency or PWM mode
          );

  zt4.setCompare(0, compare);
  zt4.setCallback(true, TC_CALLBACK_CC_CHANNEL0, Timer4Callback0);
  zt4.enable(true);

  
}

void loop() {

int numsamples = 100;
int sample_delay = 10; // milliseconds

float gain = 1000.;

 // V12B - V12C
 // 4p 6 - 4p 2
 // A3 - A4

 // V23B - V23C
 // 4p 1 - 4p 7
 // A5 - A2
 
 // TIB - TIC
// 4p 9 - 4 p 8
// A0 - A 1

float rsum = 0.;
float tisum = 0.;
float v12sum = 0.;
float v23sum = 0.;


for (int i=0;i<numsamples;i++) {
  

 int v12b = analogRead(A3);
 int v12c = analogRead(A4);

 int v23b = analogRead(A5);
 int v23c = analogRead(A2);

 int tib = analogRead(A0);
 int tic = analogRead(A1);

 float v12 = (float(v12c) - float(v12b))/4096.*3.3;

 
 v12sum=v12sum + v12;
 // Serial.print(v12);
 //Serial.print(",");
 
 float v23 = (float(v23c) - float(v23b))/4096.*3.3;

 
 v23sum=v23sum+v23;
  //Serial.print(v23sum);
 //Serial.print(",");
 
 float ti = (float(tic) - float(tib))/4096.*3.3;
 
 tisum=tisum+ti;
 //Serial.print(tisum);
 //Serial.println();
 
 delay(sample_delay);
 
}

float tiave = tisum / float(numsamples);
float v23ave = v23sum / float(numsamples);
float rave = float(v23ave) / (float(tiave) / gain);

Serial.print(v23ave,4);
Serial.print(",");
Serial.print(tiave,4);
Serial.print(",");
Serial.print(rave,4);
Serial.println();

 /*
 Serial.print(v12);
 Serial.print(",");
 Serial.print(v23);
 Serial.print(",");
 Serial.print(ti);
 Serial.print(",");
 Serial.print(r);
 Serial.println();
 */
 
  delay(100);
}

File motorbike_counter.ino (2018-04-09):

  REG_GCLK_CLKCTRL = (uint16_t) (GCLK_CLKCTRL_CLKEN | GCLK_CLKCTRL_GEN_GCLK0 | 0x1B) ;
  while (GCLK->STATUS.bit.SYNCBUSY == 1); // wait for sync

  // The type cast must fit with the selected timer mode
  TcCount16* TC = (TcCount16*) TC3; // get timer struct

  TC->CTRLA.reg &= ~TC_CTRLA_ENABLE;   // Disable TC (to enable configuration mode)
  while (TC->STATUS.bit.SYNCBUSY == 1); // wait for sync
  TC->CTRLA.reg |= TC_CTRLA_MODE_COUNT16;  // Set Timer counter Mode to 16 bits
  while (TC->STATUS.bit.SYNCBUSY == 1); // wait for sync
  TC->CTRLA.reg |= TC_CTRLA_WAVEGEN_MFRQ; // Set TC as  Match Frq
  while (TC->STATUS.bit.SYNCBUSY == 1); // wait for sync
  TC->CTRLA.reg |= TC_CTRLA_PRESCALER_DIV256;   // Set prescaler
  while (TC->STATUS.bit.SYNCBUSY == 1); // wait for sync
  TC->CC[0].reg = 18743; // 18743 OK
  while (TC->STATUS.bit.SYNCBUSY == 1); // wait for sync

  TC->INTENSET.reg = 0;              // disable all interrupts
  TC->INTENSET.bit.MC0 = 1;          // enable compare match to CC0

  // Enable InterruptVector
  NVIC_EnableIRQ(TC3_IRQn); // interrupt > TC3_Handler(){}

  TC->CTRLA.reg |= TC_CTRLA_ENABLE; // Enable TC (configuration mode finished)
  while (TC->STATUS.bit.SYNCBUSY == 1); // wait for sync

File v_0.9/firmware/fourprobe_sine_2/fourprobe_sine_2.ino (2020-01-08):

#include <Arduino.h>
#include "Adafruit_ZeroTimer.h" // https://github.com/dwblair/Adafruit_ZeroTimer

int updateIndex = 0;
int updateInterval = 10000;

float myFrequency=10000;

uint8_t  sine_wave[256] = {
  0x80, 0x83, 0x86, 0x89, 0x8C, 0x90, 0x93, 0x96,
  0x99, 0x9C, 0x9F, 0xA2, 0xA5, 0xA8, 0xAB, 0xAE,
  0xB1, 0xB3, 0xB6, 0xB9, 0xBC, 0xBF, 0xC1, 0xC4,
  0xC7, 0xC9, 0xCC, 0xCE, 0xD1, 0xD3, 0xD5, 0xD8,
  0xDA, 0xDC, 0xDE, 0xE0, 0xE2, 0xE4, 0xE6, 0xE8,
  0xEA, 0xEB, 0xED, 0xEF, 0xF0, 0xF1, 0xF3, 0xF4,
  0xF5, 0xF6, 0xF8, 0xF9, 0xFA, 0xFA, 0xFB, 0xFC,
  0xFD, 0xFD, 0xFE, 0xFE, 0xFE, 0xFF, 0xFF, 0xFF,
  0xFF, 0xFF, 0xFF, 0xFF, 0xFE, 0xFE, 0xFE, 0xFD,
  0xFD, 0xFC, 0xFB, 0xFA, 0xFA, 0xF9, 0xF8, 0xF6,
  0xF5, 0xF4, 0xF3, 0xF1, 0xF0, 0xEF, 0xED, 0xEB,
  0xEA, 0xE8, 0xE6, 0xE4, 0xE2, 0xE0, 0xDE, 0xDC,
  0xDA, 0xD8, 0xD5, 0xD3, 0xD1, 0xCE, 0xCC, 0xC9,
  0xC7, 0xC4, 0xC1, 0xBF, 0xBC, 0xB9, 0xB6, 0xB3,
  0xB1, 0xAE, 0xAB, 0xA8, 0xA5, 0xA2, 0x9F, 0x9C,
  0x99, 0x96, 0x93, 0x90, 0x8C, 0x89, 0x86, 0x83,
  0x80, 0x7D, 0x7A, 0x77, 0x74, 0x70, 0x6D, 0x6A,
  0x67, 0x64, 0x61, 0x5E, 0x5B, 0x58, 0x55, 0x52,
  0x4F, 0x4D, 0x4A, 0x47, 0x44, 0x41, 0x3F, 0x3C,
  0x39, 0x37, 0x34, 0x32, 0x2F, 0x2D, 0x2B, 0x28,
  0x26, 0x24, 0x22, 0x20, 0x1E, 0x1C, 0x1A, 0x18,
  0x16, 0x15, 0x13, 0x11, 0x10, 0x0F, 0x0D, 0x0C,
  0x0B, 0x0A, 0x08, 0x07, 0x06, 0x06, 0x05, 0x04,
  0x03, 0x03, 0x02, 0x02, 0x02, 0x01, 0x01, 0x01,
  0x01, 0x01, 0x01, 0x01, 0x02, 0x02, 0x02, 0x03,
  0x03, 0x04, 0x05, 0x06, 0x06, 0x07, 0x08, 0x0A,
  0x0B, 0x0C, 0x0D, 0x0F, 0x10, 0x11, 0x13, 0x15,
  0x16, 0x18, 0x1A, 0x1C, 0x1E, 0x20, 0x22, 0x24,
  0x26, 0x28, 0x2B, 0x2D, 0x2F, 0x32, 0x34, 0x37,
  0x39, 0x3C, 0x3F, 0x41, 0x44, 0x47, 0x4A, 0x4D,
  0x4F, 0x52, 0x55, 0x58, 0x5B, 0x5E, 0x61, 0x64,
  0x67, 0x6A, 0x6D, 0x70, 0x74, 0x77, 0x7A, 0x7D
};

volatile uint8_t t = 0;


Adafruit_ZeroTimer zt4 = Adafruit_ZeroTimer(4);

void TC4_Handler(){
  Adafruit_ZeroTimer::timerHandler(4);
}


void Timer4Callback0()
{

t++;
  
}

void setup_timer(float freq4) {

  
   // Set up the flexible divider/compare
  uint8_t divider  = 1;
  uint16_t compare = 0;
  tc_clock_prescaler prescaler = TC_CLOCK_PRESCALER_DIV1;


  if ((freq4 < 24000000) && (freq4 > 800)) {
    divider = 1;
    prescaler = TC_CLOCK_PRESCALER_DIV1;
    compare = 48000000/freq4;
  } else if (freq4 > 400) {
    divider = 2;
    prescaler = TC_CLOCK_PRESCALER_DIV2;
    compare = (48000000/2)/freq4;
  } else if (freq4 > 200) {
    divider = 4;
    prescaler = TC_CLOCK_PRESCALER_DIV4;
    compare = (48000000/4)/freq4;
  } else if (freq4 > 100) {
    divider = 8;
    prescaler = TC_CLOCK_PRESCALER_DIV8;
    compare = (48000000/8)/freq4;
  } else if (freq4 > 50) {
    divider = 16;
    prescaler = TC_CLOCK_PRESCALER_DIV16;
    compare = (48000000/16)/freq4;
  } else if (freq4 > 12) {
    divider = 64;
    prescaler = TC_CLOCK_PRESCALER_DIV64;
    compare = (48000000/64)/freq4;
  } else if (freq4 > 3) {
    divider = 256;
    prescaler = TC_CLOCK_PRESCALER_DIV256;
    compare = (48000000/256)/freq4;
  } else if (freq4 >= 0.75) {
    divider = 1024;
    prescaler = TC_CLOCK_PRESCALER_DIV1024;
    compare = (48000000/1024)/freq4;
  } else {
    Serial.println("Invalid freq4uency");
    while (1) delay(10);
  }

  zt4.enable(false);
  zt4.configure(prescaler,       // prescaler
          TC_COUNTER_SIZE_16BIT,       // bit width of timer/counter
          TC_WAVE_GENERATION_MATCH_PWM // freq3uency or PWM mode
          );

  zt4.setCompare(0, compare);
  zt4.setCallback(true, TC_CALLBACK_CC_CHANNEL0, Timer4Callback0);
  zt4.enable(true);

}


void setup() {

analogWriteResolution(8);

analogReadResolution(12);

setup_timer(myFrequency);
}

void loop() {

int pot = analogRead(A1);
updateIndex++;



// update the frequency
if (updateIndex > updateInterval) {

zt4.enable(false);
int out = map(pot,0,4096,1000,10000);
setup_timer((float) out);
updateIndex=0;
}


analogWrite(A0, sine_wave[t]);
}
